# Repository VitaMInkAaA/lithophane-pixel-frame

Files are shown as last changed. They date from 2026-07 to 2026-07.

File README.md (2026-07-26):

# Lithophane Pixel Frame

A 3D-printed picture frame with a **7 × 9 WS2812 pixel matrix**, a capacitive touch
button and a self-hosted web panel — including a full **pixel-art animation editor**
that runs in your phone's browser. No cloud, no app, no external services: the
Raspberry Pi Pico W serves everything itself.

Draw frame by frame on your phone, apply effects, hit play, and the drawing appears
on the lamp in real time.






> 🇵🇱 Pełna dokumentacja po polsku: **[DOKUMENTACJA.md](DOKUMENTACJA.md)**

---

## Features

- **17 built-in modes** — fire, candle flame, aurora, plasma, rainbow, rainbow from
  the corner, snow, Matrix rain, sparkles, fireflies, trailing balls, bouncing cube,
  fireworks, beating heart, breathing, solid colour and a calibration pattern —
  all written for a portrait 7 × 9 grid
- **Pixel-art editor in the browser** — draw with your finger, flood fill,
  eyedropper, undo/redo, onion skin of the previous frame
- **Frame-by-frame animation** — per-frame duration, timeline with thumbnails,
  live preview on both the phone and the lamp
- **Effects** — brightness, invert, desaturate, saturate, contrast, tint;
  applied to one frame, a range, or the whole animation
- **Frame generators** — fade in/out, cross-fade, blink, auto-movement,
  ping-pong, reverse, speed up/down
- **Gallery** — save animations on the device, pick which ones the touch button
  cycles through
- **Touch control** — 1/2/3/4 clicks and press-and-hold ramps for brightness and speed
- **Zero-config networking** — connects to your Wi-Fi, falls back to its own
  access point with a captive portal, reachable at `lampka.local`
- **Auto-off timer**, on-device event log, and a self-healing HTTP listener
- **No external libraries.** Everything runs on stock MicroPython.

---

## Bill of materials

| # | Part | Qty | Notes |
|---|---|---|---|
| 1 | **Raspberry Pi Pico W** | 1 | Wi-Fi is required. Pico 2 W works too. Plain Pico won't — no radio. |
| 2 | **WS2812B LED strip** | 63 LEDs | Cut into segments and glued in a serpentine. 60 LEDs/m gives ~16.7 mm pitch → ~117 × 150 mm active area. |
| 3 | **TTP223 capacitive touch module** | 1 | Momentary mode (factory default). Latching mode will **not** work. |
| 4 | **5 V power supply** | 1 | ≥ 3 A for full brightness, 2 A is enough at the default 40 %. |
| 5 | **Wire** | — | AWG 20 (0.5 mm²) for power, AWG 24–26 for data. |
| 6 | **3D-printed enclosure** | 3 parts | STL files in [`cad/`](cad/) — main case, back cover, Pico cover. |
| 7 | **Lithophane panel** | 1 | Printed from your own photo, see below. |

### Optional

The reference build runs fine without these. They are common good practice and worth
adding if you hit the matching problem:

| Part | What it is for |
|---|---|
| **Schottky diode** 1N5817 / SS14, ≥ 1 A | On `VSYS`, so the external supply and USB can both be connected at once |
| **Resistor 330 Ω** | In series with the data line at the first LED — damps reflections on long data runs |
| **Capacitor 470–1000 µF**, ≥ 6.3 V | Across 5 V and GND at the matrix input — absorbs current surges when many LEDs switch at once |
| **74AHCT125** level shifter | Only if the LEDs misbehave on 3.3 V data (see [Troubleshooting](#troubleshooting)) |

---

## 3D-printed parts

Everything for the enclosure lives in **[`cad/`](cad/)**:

| File | What it is |
|---|---|
| `stl/case-main.stl` | Main enclosure — holds the matrix and the electronics |
| `stl/cover.stl` | Back cover |
| `stl/cover-pico.stl` | Cover over the Pico |

Printed flat, the parts need no supports. Material and colour are up to you — light
passes through the lithophane, not through the enclosure.

The **lithophane panel itself is not in the repository** — you generate it from your
own photo, as described below.

---

## The lithophane panel

The frame is built for a **portrait photo in 3:4 proportion** — straight out of an
iPhone, or any image with the same aspect ratio. A landscape or square photo will not
fit the frame; crop it to portrait 3:4 first.

Generate the model with **[itslitho](https://tool.itslitho.com/CreateModel)** using
these settings:

| Section | Setting | Value |
|---|---|---|
| **Shape** | Shape | `Arc` |
| | Height | `150 mm` |
| | Width | *auto* (≈ 109.5 mm — derived from the photo's aspect ratio) |
| | Angle | `50°` |
| | Min thick | `0.8 mm` |
| | Max thick | `3.2 mm` |
| | Crop / Inside | off |
| **Frame** | Frame | `Frame` |
| | Thickness | `3 mm` |
| | Depth | `4 mm` |
| | Angle | `45°` |
| | Advanced | off |
| **Quality** | mm per pixel | `0.1 mm` |
| | Preview model | `Low` |
| **Attributes** | Enable lamp / Close bottom / Nightlight | all off |
| **Model** | Lighting | `Back lighted` |
| | Light intensity | `5 – 95 %` |
| | Auto update / Cura fix | on |
| **Image** | Positive image | on |
| | Flip / Mirror image | off |
| | Placement horizontal / vertical | `50 % / 50 %` |
| | Zoom factor | `100 %` |

Notes:

- **Min 0.8 mm / max 3.2 mm** is what makes the image readable when backlit — thin
  spots let light through, thick ones block it. Thinner than 0.8 mm becomes fragile
  and prints badly.
- `Back lighted` matters: the tool inverts the depth map for a panel lit from behind,
  which is exactly how the LED matrix sits.
- At `0.1 mm per pixel` the exported STL is around **165 MB**. That is normal for a
  lithophane — slicing it takes a while.
- Print in **white or natural PLA**, no supports needed for the arc shape. The curve
  is deliberate: it keeps the panel away from the LEDs so individual pixels blur into
  an even glow instead of showing as dots.

---

## Wiring

| Signal | Pico W pin | Notes |
|---|---|---|
| Matrix `DIN` | **GP0** — pin 1 | Optionally through a 330 Ω resistor |
| TTP223 `OUT` | **GP2** — pin 4 | |
| TTP223 `VCC` | **3V3(OUT)** — pin 36 | **Not 5 V** — Pico GPIO is not 5 V tolerant |
| Common ground | **GND** — pin 38 | Supply, Pico and matrix must share ground |
| Pico power | **VSYS** — pin 39 | Optionally via a Schottky diode |
| Matrix power | Straight from the PSU | Separate pair of wires |

```
                    ┌──────────── (thick pair) ──────► matrix  5V / GND
   5 V PSU ─────────┤
                    └───────────────────────────────► VSYS (pin 39)
                        (optional Schottky here, so USB
                         can stay plugged in at the same time)

   Pico GP0 ──────────────────────────────────► DIN (first LED)
   Pico GND ──────────────────────────────────► GND  (shared!)
```

### Power notes

- **Never feed 5 V into `VBUS` (pin 40)** — it is wired directly to the USB
  connector and would back-feed your computer's port.
- **Never feed 5 V into `3V3(OUT)` (pin 36)** — that pin is an output and 5 V kills it.
- Feeding `VSYS` directly works. Add a Schottky diode there if you want the external
  supply and USB connected at the same time — then the two sources can't fight
  each other.
- Wire the power in a **star** from the PSU. Don't daisy-chain the Pico behind the
  matrix: several amps of pulsing current through a thin wire cause voltage dips
  that reset the Pico mid-animation.
- 63 LEDs at full white draw ≈ **3.8 A**. The web panel shows the estimated draw
  next to the brightness slider.

### Matrix geometry

The firmware ships configured for a strip that **starts in the bottom-right corner**
(viewed from the front), runs **upwards**, turns around and comes back down — i.e.
serpentine columns of 9.

If yours is soldered differently, don't guess: open **Settings → Matrix geometry →
Wizard** in the panel. It lights individual LEDs *by strip index* (bypassing the
mapping entirely), asks two questions about what you see, and derives the correct
settings itself.

---

## Installation

You need MicroPython for **Pico W**. The `neopixel` and `network` modules ship with
the firmware — there is nothing to install.

Everything under [`firmware/`](firmware/) goes onto the device, keeping the same
layout — `.py` files in the device root, the panel in a `www` folder:

```bash
cd firmware
mpremote connect auto fs mkdir :www
mpremote connect auto fs cp *.py :
mpremote connect auto fs cp www/index.html www/style.css www/app.js :www/
mpremote connect auto reset
```

Using Thonny: copy the contents of `firmware/` to the device, preserving the `www`
subfolder.

Nothing outside `firmware/` belongs on the Pico — `cad/` holds the printable models.

---

## First run

With no Wi-Fi credentials stored, the lamp creates its own network:

- **SSID:** `LED-Lampka` · **password:** `ledlampka`
- **Panel:** <http://192.168.4.1/>

Connect your phone — on most devices the panel opens by itself (captive portal).
Go to the **WiFi** tab, pick your network, enter the password. The lamp connects
**immediately, without rebooting**, and shows the result. If it fails, it tells you
*why* (`wrong password`, `network not visible`, …), keeps its own access point alive,
and stays reachable so you can fix the password on the spot.

### Finding the lamp afterwards

| Method | Address |
|---|---|
| Hostname (mDNS) | <http://lampka.local/> |
| Its own access point | <http://192.168.4.1/> |
| The matrix tells you | last two octets of the IP, digit by digit |

The matrix shows **two** octets rather than one on purpose: a router may put the
lamp on a different subnet than your phone, and a lone `144` would send you to the
wrong address.

---

## Touch control

| Gesture | Action |
|---|---|
| **1 click** | On / off |
| **2 clicks** | Next mode |
| **3 clicks** | Previous mode |
| **4 clicks** | Show IP on the matrix |
| **Press and hold** | Brightness ramp — release and hold again to reverse direction |
| **2 clicks + hold** | Animation speed, same alternating ramp |
| **3 clicks + hold 5 s** | Forget Wi-Fi and return to access-point mode |

A single click reacts after ~0.35 s — that is the window for a second click, without
which one and two clicks cannot be told apart. Wiping the Wi-Fi credentials
deliberately requires three clicks *and* a long hold, so a plain long press (which
controls brightness) can never erase your network by accident.

If your TTP223 has inverted logic (jumper), flip it in **Settings → Button** —
no rewiring needed.

---

## Web panel

**Modes** — brightness, speed, colour, mode grid. The colour tile greys out and
locks in modes that paint their own colours.

**Editor** — a full pixel-art tool:

- 7 × 9 grid mapped 1:1 to the frame, brush + palette, flood fill, eyedropper,
  eraser, undo/redo (40 steps), onion skin of the previous frame
- Frame strip with thumbnails; add, duplicate, reorder, delete, wipe all
- Per-frame duration in milliseconds
- **Effects** applied to *this frame / from here on / all frames*: brightness
  0–200 %, invert, desaturate, saturate, contrast, tint with the brush colour
- **Transforms**: shift in four directions (wrapping), mirror, rotate 180°
- **Generators**: fade in/out, cross-fade to the next frame, blink, auto-movement,
  ping-pong, reverse, ×2 faster/slower
- **Preview** plays on the phone grid and on the lamp at once; stop restores both
  the frame you were editing and what the lamp was showing before

**Gallery** — saved animations with thumbnails, plus a checklist deciding which
modes the touch button cycles through.

**Settings** — auto-off timer, hostname, access-point behaviour, matrix geometry
wizard, button logic, diagnostics.

**WiFi** — status with signal strength, every address the lamp answers on, network
scan, country code. A weak link raises a warning banner here and in Settings, since
that is where you would go to do something about it.

### Why the effects don't slow the lamp down

All image processing happens **in the browser** and is baked into pixels. The Pico
receives finished frames and does exactly what it does for a static image: one
189-byte `blit()` per frame. You can stack as many effects as you like — the cost on
the device never changes.

Limits that protect the device: **40 frames** per animation, **24 animations** in the
gallery, frame duration **40–10000 ms**, and a **64 kB** cap on request bodies.
Only the currently playing animation is held in RAM.

---

## Writing your own animation

Add a class to `animations.py` and register it in `ANIMS` — the panel picks it up
automatically:

```python
class MyAnimation(Anim):
    name = "mine"            # ASCII id used by the API
    label = "My animation"   # shown in the panel
    interval = 60            # ms between steps at 100 % speed
    uses_color = False       # True if it uses the colour picked in the panel

    def step(self):
        m = self.m
        m.clear()
        m.set(3, 4, 255, 0, 0)   # x, y, r, g, b — (0,0) is the top-left corner
```

Do not call `m.show()` or `time.sleep()` — the render loop in `lamp.py` handles both,
which is why brightness and speed work globally for every effect. Available helpers:
`clear()`, `fill()`, `set()`, `setc()`, `get()`, `add()`, `fade()`, `scale()`,
`blit()`, plus `m.w` and `m.h`.

---

## Project structure

```
firmware/            everything that goes onto the Pico
├── main.py          startup: Wi-Fi, boot signals, task launch
├── config.py        pins, matrix size, settings + settings.json
├── led_matrix.py    Matrix class: one NeoPixel object, serpentine mapping, brightness
├── animations.py    all animations (Anim base class + ANIMS registry)
├── lamp.py          lamp state, render loop, auto-off, gesture handling
├── touch.py         TTP223: click counting and press-and-hold
├── netmgr.py        Wi-Fi connect, access point, scan, reconnect watchdog
├── webserver.py     HTTP server + REST API (uasyncio, no external libraries)
├── dns.py           DNS responder for the captive portal
├── frames.py        gallery of saved animations (anims/ directory)
├── glyphs.py        3 × 5 font for showing the IP on the matrix
├── logger.py        event log: serial always, log.txt optionally
└── www/             panel: index.html, style.css, app.js
cad/                 enclosure: STL files, ready to print
```

`settings.json`, `anims/` and `log.txt` are created on the device at runtime, which
is why they are in `.gitignore`.

---

## Troubleshooting

| Symptom | Cause and fix |
|---|---|
| Animations look shredded or move the wrong way | Wrong geometry — run **Settings → Geometry → Wizard** |
| Random flicker, wrong colours | Power. Check the capacitor, common ground and wire gauge. If it persists, add a 74AHCT125 level shifter on the data line |
| Pico resets on bright animations | PSU too weak, or the Pico is daisy-chained behind the matrix — wire in a star |
| Lamp has an IP but the panel won't open | See below |
| `lampka.local` doesn't resolve | Your firmware lacks the mDNS responder, or the client doesn't support it. Use the IP or the access point |
| Phone can't reach it while the computer can | Compare subnets, and check for client isolation on the router |

### If the panel stops responding after hours of uptime

Three known causes, all addressed in the firmware:

1. **Wi-Fi power saving.** The CYW43 sleeps the receiver between frames and drops
   inbound packets — the lamp looks connected but is unreachable. Disabled by default.
2. **No reconnect.** After a router restart or lease expiry the lamp used to stay
   offline forever. A watchdog now checks every 20 s and reconnects.
3. **The HTTP listener dying.** In uasyncio the accept loop is an ordinary task; if
   it raises, it dies silently while animations keep running. A supervisor probes
   the port every 2 minutes and restarts the listener — no reboot, no interruption.

Enable **Settings → Diagnostics** to write events to `log.txt` on the device. Read it
with `mpremote connect auto fs cat :log.txt`, in the panel, or over serial. Each entry
is stamped with uptime, because the Pico has no battery-backed clock. The periodic
status line tells the three causes apart:

```
02:35:11  RAM 138912 B | polaczenia otwarte 0 | obsluzonych 214
```

Falling RAM means a leak; a rising open-connection count means sockets aren't being
released; a frozen served counter means requests aren't arriving at all.

More detail — including every failure mode and the reasoning behind each fix — is in
**[DOKUMENTACJA.md](DOKUMENTACJA.md)**.

---

## Development

The firmware is plain Python, so most of it runs on a desktop. The test suites
replace `machine`, `neopixel` and `network` with stubs that **validate** instead of
merely pretending — the NeoPixel stub raises if a channel leaves 0–255 or an index
falls outside the matrix, so running the animations through it catches real bugs.

- `asyncio.start_server` works on CPython, so the HTTP and DNS servers are tested
  over **real sockets** with real requests
- The button tests drive a **controlled clock**, making a 5-second hold deterministic
- The browser tests extract functions **verbatim from `firmware/www/app.js`** and run them in
  Node, so they exercise the shipped code rather than a copy

What the tests cannot prove: LED timing, current draw, real Wi-Fi behaviour, RAM
pressure and speed on a 133 MHz target, or how anything actually looks. Those need
the hardware.

---

## License

**[CC BY-NC 4.0](LICENSE)** — Creative Commons Attribution-NonCommercial 4.0
International.

Build it for yourself, modify it, publish your version with credit, use it in
workshops and education. **Selling assembled lamps, kits or printed panels requires
written permission** from the copyright holder.

Note that CC BY-NC is deliberately *not* an OSI-approved open-source license — the
non-commercial restriction is the point. Third-party components (MicroPython, the
Pico W SDK, external tools referenced here) keep their own licenses.

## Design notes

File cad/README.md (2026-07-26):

# CAD — model obudowy / enclosure model

Pliki do druku 3D. **3D-printable parts.**

| Plik / File | Co to / What it is |
|---|---|
| `stl/case-main.stl` | Obudowa główna — mieści matrycę i elektronikę. *Main enclosure, holds the matrix and electronics.* |
| `stl/cover.stl` | Pokrywa tylna. *Back cover.* |
| `stl/cover-pico.stl` | Pokrywa nad Pico. *Cover over the Pico.* |

Folder nazywa się `cad`, a nie `fusion`, bo pliki STL otworzy i wydrukuje każdy,
niezależnie od tego, w czym projektuje.

*The folder is called `cad`, not `fusion`: STL files are usable by anyone, whatever
CAD package they run.*

## Druk / Printing

Części nie wymagają podpór drukowane płasko. Materiał i kolor dowolne — światło idzie
przez litofanię, nie przez obudowę.

*No supports needed when printed flat. Material and colour are up to you — light
passes through the lithophane, not through the enclosure.*

## Panel z litofanią / The lithophane panel

**Nie ma go tutaj i nie powinno być** — generujesz go ze swojego zdjęcia. Ustawienia
narzędzia [itslitho](https://tool.itslitho.com/CreateModel) są w
[README](../README.md#the-lithophane-panel).

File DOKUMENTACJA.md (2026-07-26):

# LED Lampka — ramka 7 × 9 na Raspberry Pi Pico W

Drukowana w 3D ramka z matrycą WS2812 **7 szeroko × 9 wysoko (63 diody)**, przyciskiem
dotykowym TTP223 i panelem WWW. Sterowanie dotykiem albo z telefonu — bez chmury,
wszystko lokalnie na Pico.

## Podłączenie

| Sygnał | Pico | Uwagi |
|---|---|---|
| DIN matrycy | **GP0** (pin 1) | opcjonalnie rezystor 330 Ω w szereg przy pierwszej diodzie |
| OUT z TTP223 | **GP2** (pin 4) | |
| VCC TTP223 | **3V3(OUT)** (pin 36) | **nie 5 V** — GPIO Pico nie jest 5 V tolerant |
| GND wszystkiego | GND (pin 38) | masa wspólna z zasilaczem |
| zasilanie Pico | **VSYS** (pin 39) | opcjonalnie przez diodę Schottky |
| zasilanie matrycy | osobna para przewodów wprost od zasilacza | |

### Elementy opcjonalne

Referencyjny egzemplarz działa bez nich. To dobra praktyka, warta dołożenia,
jeśli natkniesz się na odpowiadający jej problem:

| Element | Po co |
|---|---|
| **dioda Schottky** 1N5817 / SS14, ≥ 1 A | na `VSYS`, żeby dało się mieć podłączony zasilacz i USB jednocześnie |
| **rezystor 330 Ω** | w szereg z linią danych przy pierwszej diodzie — tłumi odbicia przy dłuższym przewodzie |
| **kondensator 470–1000 µF**, ≥ 6,3 V | między 5 V i GND na wejściu matrycy — przyjmuje skoki prądu przy przełączaniu wielu diod naraz |
| **konwerter poziomów 74AHCT125** | tylko jeśli diody wariują przy danych 3,3 V |

Taśma naklejona wężykiem: **pierwsza dioda w prawym dolnym rogu** (patrząc na ramkę
z przodu), pasek idzie **w górę**, zawraca i schodzi w dół — czyli kolumnami po 9.
Tak jest ustawione fabrycznie w `config.py`. Kod przelicza to na współrzędne (x, y)
z zerem w lewym górnym rogu, więc animacje pisze się normalnie, bez myślenia o wężyku.
Jeśli Twoja ramka jest polutowana inaczej, nie zgaduj — uruchom **Kreator** w panelu
(Ustawienia → Geometria), odpowiedz na dwa pytania o to, co widzisz, i ustawi się sam.

63 diody na pełnej bieli to ~3,8 A. Domyślna jasność 40 % daje ~1,5 A, a panel pokazuje
szacowany pobór przy każdej zmianie suwaka.

## Model do druku

Wszystko do obudowy leży w folderze **`cad/`**:

| Plik | Co to |
|---|---|
| `stl/case-main.stl` | obudowa główna — mieści matrycę i elektronikę |
| `stl/cover.stl` | pokrywa tylna |
| `stl/cover-pico.stl` | pokrywa nad Pico |

Drukowane płasko części nie wymagają podpór. Materiał i kolor dowolne — światło idzie
przez litofanię, nie przez obudowę.

Folder nazywa się `cad`, a nie `fusion`, bo pliki mają służyć też komuś bez
Fusion 360. Nazwa związana z jednym programem sugerowałaby, że bez niego nie ma tu
czego szukać.

**Samego panelu z litofanią w repozytorium nie ma** — generujesz go ze swojego
zdjęcia, patrz niżej.

## Litofania (panel ze zdjęciem)

Ramka jest zrobiona pod **zdjęcie pionowe w proporcji 3:4** — prosto z iPhone'a albo
dowolne o tej samej proporcji. Zdjęcie poziome ani kwadratowe **nie zmieści się**
w ramce; najpierw przytnij je do pionu 3:4.

Model generujesz na **<https://tool.itslitho.com/CreateModel>** z takimi ustawieniami:

| Sekcja | Ustawienie | Wartość |
|---|---|---|
| **Shape** | Shape | `Arc` |
| | Height | `150 mm` |
| | Width | *automatycznie* (~109,5 mm — wynika z proporcji zdjęcia) |
| | Angle | `50°` |
| | Min Thick | `0,8 mm` |
| | Max Thick | `3,2 mm` |
| | Crop / Inside | wyłączone |
| **Frame** | Frame | `Frame` |
| | Thickness | `3 mm` |
| | Depth | `4 mm` |
| | Angle | `45°` |
| | Advanced | wyłączone |
| **Quality** | mm per pixel | `0,1 mm` |
| | Preview Model | `Low` |
| **Attributes** | Enable lamp / Close bottom / Nightlight | wszystko wyłączone |
| **Model** | Lighting | `Back lighted` |
| | Light intensity | `5 – 95 %` |
| | Auto update / Cura fix | włączone |
| **Image** | Positive image | włączone |
| | Flip / Mirror image | wyłączone |
| | Placement horizontal / vertical | `50 % / 50 %` |
| | Zoom factor | `100 %` |

Dlaczego akurat tak:

- **0,8–3,2 mm grubości** to jest cały mechanizm litofanii — cienkie miejsca
  przepuszczają światło, grube blokują. Poniżej 0,8 mm panel robi się kruchy i źle
  się drukuje.
- `Back lighted` jest istotne: narzędzie odwraca wtedy mapę grubości pod panel
  podświetlany od tyłu, czyli dokładnie tak, jak siedzi matryca.
- Przy `0,1 mm na piksel` plik STL ma około **165 MB**. To normalne dla litofanii,
  ale krojenie chwilę trwa.
- Drukuj w **białym albo naturalnym PLA**, łuk nie wymaga podpór. Wygięcie panelu
  jest celowe: odsuwa go od diod, dzięki czemu pojedyncze piksele rozmywają się
  w równą poświatę zamiast świecić jako kropki.

## Wgranie na Pico

Potrzebny MicroPython dla **Pico W** (biblioteki `neopixel` i `network` są w firmware,
nic nie doinstalowujesz).

Na Pico trafia **cała zawartość folderu `firmware/`**, z zachowaniem układu — pliki
`.py` do katalogu głównego, panel do katalogu `www`:

```bash
cd firmware
mpremote connect auto fs mkdir :www
mpremote connect auto fs cp *.py :
mpremote connect auto fs cp www/index.html www/style.css www/app.js :www/
mpremote connect auto reset
```

W Thonnym: skopiuj zawartość `firmware/` na urządzenie, zachowując podkatalog `www`.

Nic spoza `firmware/` na Pico nie idzie — `cad/` to modele do druku.

## Pierwsze uruchomienie

Bez zapisanego hasła lampka stawia własną sieć:

- SSID **LED-Lampka**, hasło **ledlampka**
- panel: **http://192.168.4.1/**

Podłącz się telefonem, wejdź w zakładkę **WiFi**, wybierz swoją sieć, podaj hasło →
lampka próbuje się połączyć **od razu, bez restartu**, a wynik widać w polu „Stan".
Jeśli się nie uda, pokazuje **dlaczego** („złe hasło", „nie widzę tej sieci"…),
nie traci własnej sieci i panel zostaje dostępny, więc możesz od razu poprawić hasło.

### Gdy lampka nie chce się połączyć

| Komunikat | Co z tym zrobić |
|---|---|
| złe hasło | literówka; hasła WiFi rozróżniają wielkość liter |
| nie widzę tej sieci | **Pico W obsługuje wyłącznie 2,4 GHz** — sieć 5 GHz jest dla niego niewidzialna, nawet jeśli telefon ją widzi. Sprawdź też kod kraju niżej |
| router odrzucił połączenie | filtr adresów MAC albo pełna lista klientów na routerze |
| nie zdążyłem w wyznaczonym czasie | słaby sygnał — spróbuj bliżej routera |
| sieć nie przydzieliła adresu | problem z DHCP na routerze |

**Kod kraju** (zakładka WiFi, domyślnie `PL`) decyduje o dozwolonych kanałach.
Bez niego Pico trzyma się kanałów 1–11, a routery w Polsce potrafią stać na 12 lub 13
— takiej sieci lampka **w ogóle nie zobaczy**, i to wygląda dokładnie jak „nie widzę
tej sieci". Jeśli sieć jest widoczna na telefonie, a lampka jej nie znajduje,
to jest pierwszy podejrzany.

## Jak wejść do panelu nie znając adresu IP

Trzy niezależne drogi — jeśli jedna zawiedzie, zostają dwie:

**1. Nazwa lampki (mDNS): http://lampka.local/**
Nazwę zmienisz w Ustawieniach. Działa bez zaglądania do rutera. iPhone i Mac
obsługują to od zawsze (Bonjour), Windows 10/11 i Android 12+ też. Zastrzeżenie:
wymaga firmware'u z odpowiedzią mDNS — buildy MicroPythona dla Pico W zwykle ją mają,
ale nie sprawdzę tego bez Twojego sprzętu. Po starcie lampka wypisuje na porcie
szeregowym dokładny adres, pod którym się ogłasza.

**2. Własna sieć lampki: http://192.168.4.1/**
Gdy lampka nie ma z czym się połączyć, sama stawia AP `LED-Lampka` — podłączasz
telefon i wchodzisz na `192.168.4.1`. Działa bez rutera i bez nazwy .local.

Opcja *„Trzymaj własną sieć lampki cały czas"* (domyślnie włączona) utrzymuje ten AP
**równolegle** z domowym WiFi — drugie, niezależne wejście do panelu, przydatne tam,
gdzie nie masz dostępu do rutera. Zastrzeżenie: Pico W dzieli jedno radio między oba
interfejsy, więc na niektórych routerach potrafi to rozchwiać połączenie. Jeśli lampka
ma poprawny adres, a panel nie odpowiada — to jeden z podejrzanych, spróbuj wyłączyć.

**3. Panel otwiera się sam po podłączeniu do sieci lampki**
Domyślnie włączone (Ustawienia → *„Otwieraj panel sam po podłączeniu"*). Telefon po
połączeniu z siecią `LED-Lampka` sprawdza dostęp do internetu, a lampka odpowiada na
każde pytanie DNS swoim adresem i odbija zapytanie na panel — system pokazuje go od
razu, jak w hotelowym WiFi.

Działa **wyłącznie w czystym trybie AP**, czyli gdy lampka nie jest w żadnej sieci.
Po wejściu do domowego WiFi serwer DNS się nie uruchamia — odpowiadanie „każda nazwa
= 192.168.4.1" na cudzej sieci zepsułoby internet pozostałym urządzeniom.

**4. Lampka sama pokazuje swój adres**
Po połączeniu z WiFi matryca wyświetla **dwa ostatnie człony** adresu, rozdzielone
poziomą kreską — np. `1`,`7`,`8`, kreska, `1`,`4`,`4` znaczy `192.168.178.144`.
Dwa człony, a nie jeden, bo router potrafi wpuścić lampkę do innej podsieci niż ta,
w której jest Twój telefon — wtedy samo `144` prowadziłoby pod zły adres.

Awaryjnie: **4 kliknięcia** pokazują końcówkę IP na matrycy w dowolnym momencie,
a **3 kliknięcia + przytrzymanie 5 s** czyszczą zapisane WiFi i lampka wraca do
czystego trybu AP pod `192.168.4.1`.

Sygnały po starcie:

| Błysk | Znaczenie |
|---|---|
| słaby niebieski | kod wystartował |
| żółty | łączę się z zapisaną siecią |
| zielony | jest WiFi, potem matryca pokazuje **dwa ostatnie człony IP** |
| dwa niebieskie | tryb AP |
| trzy czerwone | wyjątek w kodzie (szczegóły na porcie szeregowym) |

## Sterowanie dotykiem

| Gest | Efekt |
|---|---|
| **1 klik** | włącz / wyłącz |
| **2 kliki** | następny tryb (gdy zgaszona — zapala) |
| **3 kliki** | poprzedni tryb |
| **4 kliki** | pokaż końcówkę IP na matrycy |
| **przytrzymanie** | jasność — rampa w górę; puszczasz i trzymasz znowu, żeby zejść w dół |
| **2 kliki + przytrzymanie** | szybkość animacji, tak samo naprzemiennie |
| **3 kliki + przytrzymanie 5 s** | zapomnij WiFi i wróć do trybu AP |

Jak to działa w praktyce: pojedynczy klik reaguje po ~0,35 s, bo tyle trwa okno na
dołożenie drugiego kliknięcia — inaczej nie da się odróżnić jednego od dwóch.
Rampa jasności rusza po 0,5 s trzymania i idzie ~4 % na 0,1 s, czyli pełen przejazd
od 1 % do 100 % trwa około 2,5 s. Kierunek przełącza się po każdym puszczeniu, a po
dojściu do końca zakresu następne trzymanie zawsze zawraca. Jasność nie schodzi
poniżej 1 %, żeby lampka nie „zgasła" bez wyłączenia.

Gest kasowania WiFi celowo wymaga trzech kliknięć i dopiero potem 5 s trzymania —
samo długie trzymanie steruje jasnością i nie ma szans przypadkiem wyczyścić sieci.

Jeśli Twój moduł TTP223 ma odwróconą logikę (zworka), przełącz to w panelu w
**Ustawienia → Przycisk i start** — nic nie trzeba przelutowywać.

## Panel WWW

**Animacje** — jasność, szybkość, kolor (paleta + własny picker), siatka trybów.

**Edytor** — pełne narzędzie do pixel artu i animacji klatka po klatce.

*Rysowanie:* siatka 7 × 9 1:1 z ramką, pędzel z paletą, **wypełnianie obszaru**,
**pipeta** (pobiera kolor z siatki), gumka, cofnij/ponów (40 kroków wstecz).
**Duch poprzedniej klatki** pokazuje pod spodem przygaszony poprzedni kadr — bez
tego rysowanie ruchu to zgadywanka. Klik w piksel z kolorem pędzla gasi go; kolor
pociągnięcia ustala się przy pierwszym dotkniętym pikselu, więc przeciągnięcie po
pomalowanym fragmencie go nie zjada, a zaczęte na świecącym pikselu działa jak gumka.

*Klatki:* pasek miniatur, dodaj / duplikuj / przesuń / usuń, **usuń wszystkie**
(z pytaniem o potwierdzenie, cofalne), własny czas każdej klatki w ms,
„ten czas wszystkim".

Pod siatką, w zasięgu kciuka, jest wszystko, czego używa się przy rysowaniu animacji:
strzałki **◀ ▶** do przewijania klatka po klatce ze wskaźnikiem pozycji (`3 / 12`),
przyciski **▶ Podgląd**, **+ klatka**, **duplikuj**, **Cofnij**, **Ponów** oraz
osobny rządek **← ↑ ↓ →** do przesuwania rysunku. Pełne trójkąty przewijają klatki,
cienkie strzałki przesuwają obraz — to celowo różne kształty. Przewijanie klatek
zawija się, bo animacja i tak jest pętlą.

**▶ Podgląd** odtwarza animację na siatce w telefonie, a przy zaznaczonym
*„Podgląd puszczaj też na lampce"* równocześnie na ramce — widzisz wtedy dokładnie
to samo w obu miejscach. Po odznaczeniu podgląd zostaje tylko w telefonie, a lampka
gra dalej swoje. **Stop** wraca do klatki, którą edytowałeś, a lampka do tego, co
pokazywała przed podglądem (o ile w ogóle brała udział). Podgląd niczego nie zmienia
w animacji. Przerwanie go rysowaniem, przewinięciem albo kliknięciem w inną klatkę
zatrzymuje odtwarzanie tam, gdzie jesteś, bez skakania.

*Efekty* — z wyborem zakresu **tej klatki / od tej do końca / wszystkich klatek**:
jasność suwakiem 0–200 % plus szybkie −20 % / +25 %, negatyw, odbarwienie,
nasycenie, kontrast, zabarwienie kolorem pędzla.

*Przekształcenia:* przesuwanie w czterech kierunkach (z zawijaniem), odbicie
poziome i pionowe, obrót 180°.

*Generowanie klatek:* ściemnianie, rozjaśnianie, **przenikanie do następnej klatki**,
miganie, przesuwanie (auto-animacja ruchu w zadanym kierunku), „tam i z powrotem",
odwrócenie kolejności, przyspieszenie i zwolnienie całości ×2.

**Galeria** — zapisane animacje z miniaturami: pokaż na lampce, wczytaj do edytora,
usuń. Niżej **sekwencja przycisku**: lista wszystkich trybów z checkboxami. Zaznaczone
krążą pod dwoma kliknięciami przycisku, odznaczone zostają dostępne z panelu, ale
przycisk je pomija. Domyślnie poza sekwencją jest tylko Kalibracja.

**Ustawienia** — auto-wyłączanie (włącznik + liczba minut; licznik zeruje każde
dotknięcie przycisku i każda zmiana w panelu), nazwa lampki, stały AP i automatyczne
otwieranie panelu, geometria matrycy z kreatorem, logika przycisku, restart.

Kafelek koloru **wyszarza się i blokuje** w trybach, które mają własne kolory —
działa tylko przy „Kolor stały" i „Oddech", żeby nie kręcić suwakiem bez efektu.

**WiFi** — stan wraz z siłą sygnału, wszystkie adresy pod którymi lampka odpowiada
(klikalne), skan sieci, zapis, „zapomnij sieć".

Przy słabym sygnale na górze zakładek **WiFi** i **Ustawienia** pojawia się baner
z konkretną wartością w dBm. Tylko tam — w Trybach, Edytorze i Galerii nie ma czego
z tym zrobić, więc nie zabiera miejsca. Poniżej −70 dBm ostrzeżenie jest łagodne,
poniżej progu `rssi_min` robi się czerwone i tłumaczy, że pakiety giną.

Ustawienia lądują w `settings.json`, ale zapis na flash jest zbierany i wykonywany
najwyżej raz na 5 s — klikanie przyciskiem nie zajeżdża pamięci.

## Animacje

Stare (przepisane na 7 × 9 z poprawnym mapowaniem): **Tęcza**, **Tęcza z rogu**,
**Śnieg**, **Matrix**, **Kostka**, **Świetliki**, **Kulki z ogonami**.

Nowe, dobrane pod pionową ramkę 7 × 9:

| Tryb | Dlaczego pasuje |
|---|---|
| **Ogień** | algorytm Fire2012 per kolumna — na pionowej ramce wygląda najlepiej z całej listy |
| **Płomień świecy** | ciepłe migotanie, jaśniej u dołu i na środku; tryb „lampka do pokoju" |
| **Zorza polarna** | wolne zielono-błękitne fale, spokojne światło |
| **Plazma** | gładkie przejścia kolorów, klasyk demoscenowy |
| **Iskry** | losowe błyski gasnące wykładniczo |
| **Fajerwerki** | rakieta leci w górę i wybucha — 9 rzędów wysokości robi tu robotę |
| **Bijące serce** | bitmapa 7 × 9 z podwójnym uderzeniem, dobre na prezent |
| **Oddech** | pulsowanie wybranym kolorem |
| **Kolor stały** | zwykła lampka w wybranym kolorze |
| **Kalibracja** | biała kropka wędrująca rzędami + znaczniki rogów |

Czego nie ma i dlaczego: **przewijany tekst** (7 diod szerokości to pół litery — dałoby
się tylko pionowo, mało czytelne), **reakcja na muzykę** (potrzebny moduł mikrofonu,
np. MAX9814 na ADC), **kolory z pogody** (wymaga odpytywania API w tle). Wszystkie trzy
da się dorobić na tej architekturze — animacja to jedna klasa z metodą `step()`.

## Jak dopisać własną animację

W `animations.py` dodaj klasę i wpisz ją do `ANIMS` — panel podchwyci ją sam:

```python
class MojaAnimacja(Anim):
    name = "moja"           # ASCII, identyfikator w API
    label = "Moja animacja" # to widać w panelu
    interval = 60           # ms między krokami przy szybkości 100 %

    def step(self):
        m = self.m
        m.clear()
        m.set(3, 4, 255, 0, 0)   # x, y, r, g, b — (0,0) to lewy górny róg
```

Nie wołaj `m.show()` ani `time.sleep()` — robi to pętla w `lamp.py`. Do dyspozycji
masz `m.clear()`, `fill()`, `set()`, `setc()`, `get()`, `add()`, `fade()`, `scale()`
oraz `m.w`, `m.h`.

## Co było nie tak w starej wersji

1. **Każdy plik animacji tworzył własny obiekt `NeoPixel` na GP0** — było 7 niezależnych
   buforów walczących o ten sam pasek. To dlatego jasność nie działała (komentarz
   „janosc nie dziala" na końcu starego `main.py`): `set_color()` skalowało swój bufor,
   a animacje zaraz nadpisywały diody pełnymi wartościami. Teraz jest **jeden**
   `NeoPixel` i jasność nakładana w jednym miejscu, w `Matrix.show()`.
2. Rozmiar 8 × 8 (64 diody) wpisany na sztywno w 9 plikach — teraz raz w `config.py`.
3. Niespójne mapowanie: część plików liczyła wężykiem, część liniowo. Teraz jedna
   tablica mapowania, konfigurowalna z panelu.
4. `while True` w każdym pliku — nie dało się tego użyć jako biblioteki.
5. Blokujące `time.sleep()` w pętli głównej — przy serwerze WWW to nie do przyjęcia,
   więc całość siedzi na `uasyncio`: animacje, przycisk i panel działają równolegle.
6. Stary `main.py` zapisywał tryb, przepisując `conf.py` jako kod Pythona przy każdej
   zmianie — teraz JSON, zapisywany najwyżej raz na 5 s.
7. `kub rampka.py` uznawał pozycję `[0, 0]` za „pierwsze uruchomienie", więc resetował
   animację przy każdym trafieniu w róg.

## Gdy coś nie działa

**Animacje „szatkują się", lecą w złą stronę, piksele w edytorze zapalają się nie
tam gdzie klikasz** → Ustawienia → Geometria → **Kreator**. Zapala pojedyncze diody po
numerach na taśmie (z pominięciem całego mapowania), pyta w którym rogu się zapaliły
i w którą stronę biegną, i sam wylicza wszystkie trzy ustawienia. Trzy pytania,
bez zgadywania.

Przycisk **Wzór** to sprawdzenie: poprawne mapowanie wygląda jako **biały piksel
w lewym górnym rogu**, **czerwona linia od niego w prawo** wzdłuż górnej krawędzi
i **zielona w dół** wzdłuż lewej. Nic się nie rusza — jeśli widzisz to w innych
miejscach albo poszatkowane, mapowanie jest złe.

**Diody migają losowo, złe kolory** → zasilanie. Sprawdź kondensator, wspólną masę
i przekrój przewodów. Przy 3,3 V na linii danych i 5 V na diodach czasem trzeba
konwertera poziomów albo zasilenia matrycy z 4,5 V.

**Pico się resetuje przy jaśniejszych animacjach** → zasilacz nie wyrabia albo Pico
jest podłączone za matrycą. Prowadź zasilanie gwiazdą od zasilacza.

**Przycisk reaguje odwrotnie / sam się klika** → przełącz logikę w Ustawieniach.
TTP223 potrzebuje płytki masy pod padem i nie lubi luźnego, długiego przewodu do
elektrody.

**Lampka ma adres z WiFi, ale panel nie odpowiada, a przez jej własne AP działa**
→ najpierw porównaj podsieci. Sprawdź w telefonie, jaki adres IP dostał on sam
(Android: Ustawienia → WiFi → szczegóły sieci; iPhone: WiFi → „i" przy nazwie sieci).
Jeśli telefon ma np. `192.168.1.x`, a lampka `192.168.178.x`, to **są w dwóch różnych
sieciach** i nie mają jak się widzieć — pakiety nie mają tamtędy drogi. `lampka.local`
też nie zadziała, bo mDNS jest rozgłoszeniem lokalnym i nie przechodzi między
podsieciami. Najczęstsza przyczyna: wzmacniacz zasięgu albo drugi router, który
tworzy własną sieć za NAT-em. Wtedy albo podłącz oba urządzenia do tej samej sieci,
albo po prostu korzystaj z AP lampki — po to jest.

Druga możliwość przy tych samych objawach to **izolacja klientów** na routerze
(często włączona domyślnie w sieci dla gości): urządzenia mają internet, ale nie
widzą się nawzajem. Szukaj w ustawieniach routera pozycji „izolacja klientów",
„AP isolation" albo „blokuj komunikację między urządzeniami".

**Lampka ma adres, panel działa chwilę i zamiera** → sprawdź **siłę sygnału**
w zakładce WiFi albo w logu. Poniżej −78 dBm połączenie formalnie trwa, ale ruch
przychodzący ginie i objawia się to dokładnie tak: panel się otwiera, po chwili
przestaje reagować, a odświeżenie już się nie wczytuje.

Najczęstsza przyczyna to **repeater albo mesh**: ta sama nazwa sieci leci z kilku
miejsc, a lampka przyczepia się do dalekiego nadajnika. Firmware sam temu zapobiega —
przed połączeniem skanuje eter i wybiera **konkretny, najmocniejszy** nadajnik,
zamiast zdawać się na sterownik.

Gdy sygnał spadnie poniżej progu (`rssi_min`, domyślnie −78 dBm) i utrzyma się tak
przez minutę, lampka **najpierw skanuje** i przepina się tylko wtedy, gdy naprawdę
jest do czego: kandydat musi być mocniejszy o co najmniej 6 dB. W miejscu z jednym
nadajnikiem nic nie robi — zrywanie działającego, choć słabego łącza co minutę tylko
pogorszyłoby sprawę. Zapisuje wtedy do logu:

```
sygnal slaby (-85 dBm), ale najmocniejszy dostepny nadajnik ma -85 dBm
- nie ma sensu sie przepinac, zostaje
```

i przez 10 minut nie ponawia sprawdzania, bo samo skanowanie na chwilę przerywa ruch.

Jeśli w danym miejscu sygnał jest po prostu słaby, żadne oprogramowanie tego nie
naprawi — przysuń lampkę bliżej routera albo dostaw repeater.

**Lampka jest w WiFi, ma adres, ale panel się nie otwiera** → najpewniej masz
włączone *„Trzymaj własną sieć lampki cały czas"*. Jedno radio obsługuje wtedy dwie
sieci naraz i połączenie się rozjeżdża. Wyłącz tę opcję (Ustawienia → Dostęp bez
znania adresu IP) i zrestartuj lampkę.

**Przy rysowaniu telefon przybliża stronę** → nie powinien: dwuklik jest wyłączony
przez `touch-action: manipulation`. Jeśli mimo to przybliża, masz starą wersję
`style.css` — wgraj ją ponownie. Celowe powiększenie dwoma palcami dalej działa.

**Panel wygląda inaczej niż powinien / siatka edytora jest płaska** → stara wersja
plików w pamięci przeglądarki. Pliki panelu są serwowane z `no-cache`, więc wystarczy
odświeżyć stronę; jeśli to nie pomaga, sprawdź, czy wgrałeś **wszystkie trzy** pliki
z `www/`.

**Rano/po kilku godzinach panel przestaje odpowiadać** → dwie najczęstsze
przyczyny, obie zaadresowane w kodzie:

1. **Oszczędzanie energii radia.** Układ CYW43 usypia odbiornik między ramkami
   i gubi pakiety przychodzące — lampka formalnie jest w sieci, wychodzące
   połączenia działają, ale wejść na panel się nie da. Domyślnie **wyłączone**
   (`wifi_powersave: False`, ustawiane przy każdym łączeniu). Kosztuje ~30 mA.
2. **Brak wznawiania połączenia.** Po restarcie routera, wygaśnięciu adresu albo
   zmianie kanału lampka zostawała offline do końca życia. Teraz `netmgr.watchdog`
   sprawdza stan co 20 s i sam się łączy ponownie, zapisując to w logu.

3. **Padnięcie samego nasłuchu HTTP.** W uasyncio zadanie przyjmujące połączenia
   jest zwykłym zadaniem — jeśli rzuci wyjątkiem, ginie po cichu. Animacje chodzą
   dalej, przycisk działa, a serwer po prostu przestaje odbierać. Objaw jest wtedy
   nie do odróżnienia od problemu z WiFi.

   Trzy zabezpieczenia: **dozór nasłuchu** (`Server.supervisor`) co 2 minuty puka
   do własnego portu i po dwóch nieudanych próbach restartuje nasłuch — bez
   restartu lampki i bez gubienia animacji; **limit 6 jednoczesnych połączeń**,
   żeby nie wyczerpać skończonej puli gniazd lwIP; oraz **handler wyjątków pętli
   zdarzeń**, który zapisuje do logu traceback każdego zadania, jakie padło.

   Dozór sam się kalibruje: sprawdza najpierw, czy sonda w ogóle działa na danym
   firmware (pętla zwrotna w lwIP), i jeśli nie — wyłącza się, zamiast restartować
   serwer bez powodu.

Jeśli mimo tego problem wróci, zajrzyj do logu — powie, co się stało i po ilu
godzinach.

### Co czytać w logu

Linia stanu co 5 minut wygląda tak:

```
02:35:11  RAM 138912 B | polaczenia otwarte 0 | obsluzonych 214
```

Trzy liczby rozstrzygają, która hipoteza jest prawdziwa:

| Objaw w logu | Znaczenie |
|---|---|
| RAM systematycznie spada | wyciek pamięci — log pokaże, po ilu godzinach się zaczyna |
| „połączenia otwarte" rośnie i nie wraca do zera | gniazda nie są zwalniane, pula lwIP się kończy |
| „obsłużonych" zamarza, choć wchodzisz na panel | zapytania nie dochodzą — czyli WiFi, nie serwer |
| wpis `ZADANIE PADLO` | coś rzuciło wyjątkiem; traceback mówi dokładnie co |
| wpis `nasluch nie przyjmuje polaczen` | to był serwer, i dozór go podniósł |

### Log

Ustawienia → **Diagnostyka**. Domyślnie włączony zapis do `log.txt` na Pico.
Do pliku idą tylko istotne zdarzenia (start, stan sieci, wznawianie, wolna pamięć
co 5 minut, błędy); pojedyncze wejścia na panel lecą wyłącznie na port szeregowy,
żeby nie zajeżdżać pamięci flash. Plik nie rośnie ponad ~12 kB — po przekroczeniu
starsze wpisy są obcinane.

Każdy wpis ma stempel **czasu od startu** (`gg:mm:ss`), bo Pico nie ma zegara
z baterią. To i tak najważniejsza informacja: po ilu godzinach pracy coś się stało.

Trzy sposoby odczytu:

```bash
mpremote connect auto fs cat :log.txt      # przez USB
```

- w panelu: Ustawienia → Diagnostyka → **Pokaż log**
- na porcie szeregowym na żywo (tam widać też każde zapytanie HTTP)

**Jak wyłączyć:** odznacz *„Zapisuj zdarzenia do pliku log.txt"* w Diagnostyce
i kliknij Zapisz. Port szeregowy dalej będzie pisał — to nic nie kosztuje.
Żeby wyciszyć również log zapytań HTTP na porcie szeregowym, ustaw `LOG = False`
na początku `webserver.py`. Plik usuniesz przez `mpremote connect auto fs rm :log.txt`.

**Nie wiem, jaki ma adres** → patrz „Jak wejść do panelu nie znając adresu IP" wyżej.
Najpewniejsza droga: podłącz telefon do sieci `LED-Lampka` i wejdź na `192.168.4.1`.

**`lampka.local` nie działa** → Twój firmware nie ma odpowiedzi mDNS, albo klient jej
nie obsługuje (część Androidów, przeglądarki w trybie oszczędzania danych). Wpisuj
adres z `http://` na początku, bo bez tego telefon potraktuje to jako zapytanie do
wyszukiwarki. Jeśli i tak nie idzie — zostaje AP `192.168.4.1`, który działa zawsze.

**W nowym miejscu lampka nie widzi WiFi** → sama wróci do trybu AP po ~15 s prób,
więc po prostu podłącz się do `LED-Lampka` i wpisz dane nowej sieci.

## Struktura

```
firmware/        wszystko, co ląduje na Pico
main.py          start: WiFi, sygnały, uruchomienie zadań
config.py        piny, rozmiar matrycy, ustawienia + zapis do settings.json
led_matrix.py    klasa Matrix: jeden NeoPixel, mapowanie wężyka, jasność
animations.py    wszystkie animacje (klasa Anim + rejestr ANIMS)
lamp.py          stan lampki, pętla rysowania, auto-wyłączanie, obsługa gestów
touch.py         TTP223: krótko / przytrzymanie / długie przytrzymanie
netmgr.py        łączenie z WiFi, tryb AP, skanowanie
dns.py           serwer DNS dla captive portalu (panel otwiera się sam)
logger.py        log zdarzeń: port szeregowy + opcjonalnie log.txt
webserver.py     serwer HTTP + API (uasyncio, bez bibliotek zewnętrznych)
frames.py        galeria własnych animacji (katalog anims/)
glyphs.py        czcionka 3×5 do pokazania IP na matrycy
www/             panel: index.html, style.css, app.js
                 (powyższe leżą w firmware/)
cad/             obudowa: pliki STL do druku
```

`settings.json` i katalog `anims/` tworzą się same przy pierwszym zapisie.
Sam program to ~95 kB z ~1,4 MB flasha Pico.

### Dlaczego efekty nie obciążają Pico

Cała obróbka dzieje się **w przeglądarce** i zapieka się w piksele. Na lampkę
trafiają gotowe klatki, a ona robi dokładnie to samo co przy zwykłym obrazku:
jeden `blit()` bufora 189 bajtów na klatkę. Możesz nakładać dowolnie dużo efektów
— koszt po stronie Pico jest zawsze taki sam. Cena tego rozwiązania: efekty są
nieodwracalne (po zejściu do 0 % koloru nie ma skąd go wziąć), dlatego jest
cofanie na 40 kroków.

Trzy zabezpieczenia przed zamuleniem lampki:

1. **Limit 40 klatek** — generatory nie przekraczają go po cichu, tylko dokładają
   tyle, ile się mieści, i mówią o tym wprost.
2. **Limit 64 kB na zapytanie HTTP** — większe ciało dostaje `413` bez próby
   wczytania do RAM-u. Pełna 40-klatkowa animacja waży ~16 kB, więc jest z zapasem.
3. **Do RAM-u wchodzi tylko grająca animacja** — 40 klatek to 7,5 kB buforów.

### Jak trzymane są własne animacje

Każda animacja to osobny plik `anims/<nazwa>.json`, a `anims/index.json` to spis nazw
z miniaturami. Do RAM-u ładowana jest wyłącznie ta animacja, która akurat gra —
przy 24 animacjach po 40 klatek cała galeria w pamięci by się nie zmieściła.
Piksele siedzą jako ciąg hex (`rrggbb` × 63), bo lista liczb w JSON-ie zajmuje
trzy razy więcej. Klatka na urządzeniu to gotowy bufor 189 bajtów wrzucany do matrycy
jednym `blit()`, bez przeliczania piksel po pikselu.

Limity: **40 klatek** na animację, **24 animacje** w galerii, czas klatki **40–10000 ms**.
Panel dostaje te wartości z `/api/state`, więc zmiana ich w `frames.py` od razu
przestawia też podpowiedzi w interfejsie.

## Licencja

**[CC BY-NC 4.0](LICENSE)** — uznanie autorstwa, użycie niekomercyjne.

Możesz zbudować dla siebie, przerobić, opublikować swoją wersję z podaniem źródła,
używać na warsztatach i w edukacji. **Sprzedaż gotowych lampek, zestawów albo
wydrukowanych paneli wymaga pisemnej zgody** autora.

Pamiętaj, że CC BY-NC celowo **nie jest** licencją open source w rozumieniu OSI —
ograniczenie komercyjne jest tu zamierzone. Składniki obce (MicroPython, SDK Pico W,
narzędzia zewnętrzne) mają własne licencje.

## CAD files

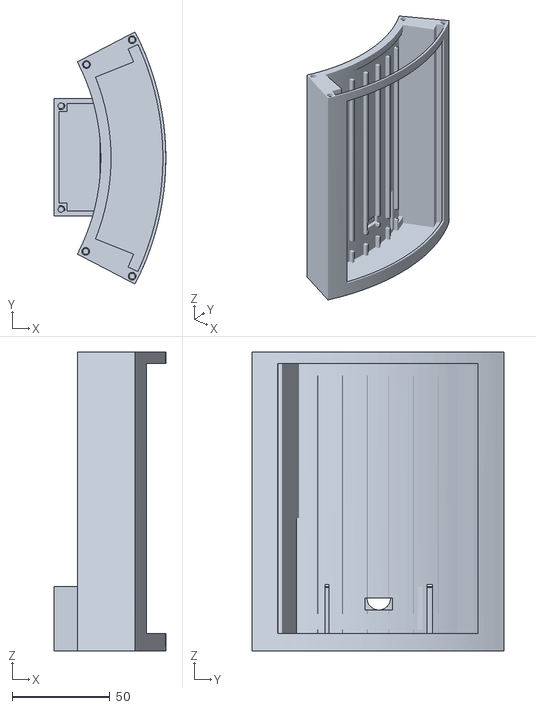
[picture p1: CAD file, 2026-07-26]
cad/stl/case-main.stl
57.2 x 129.1 x 153.0

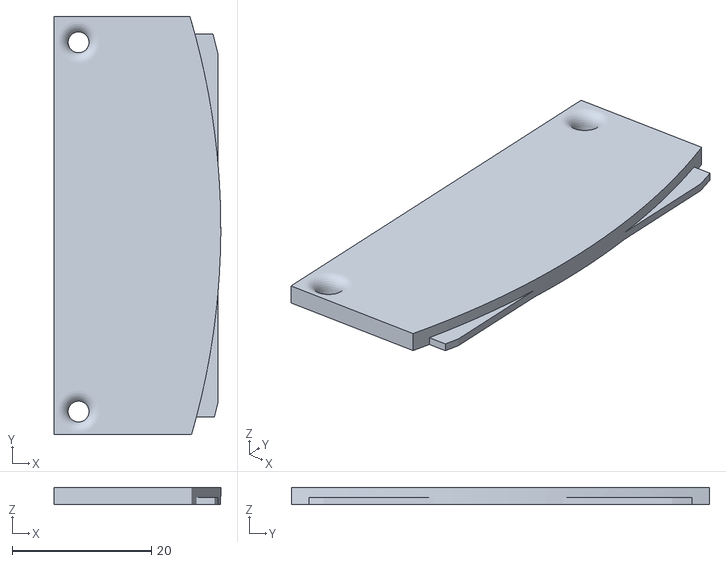
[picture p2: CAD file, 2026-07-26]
cad/stl/cover-pico.stl
23.9 x 60.0 x 2.50

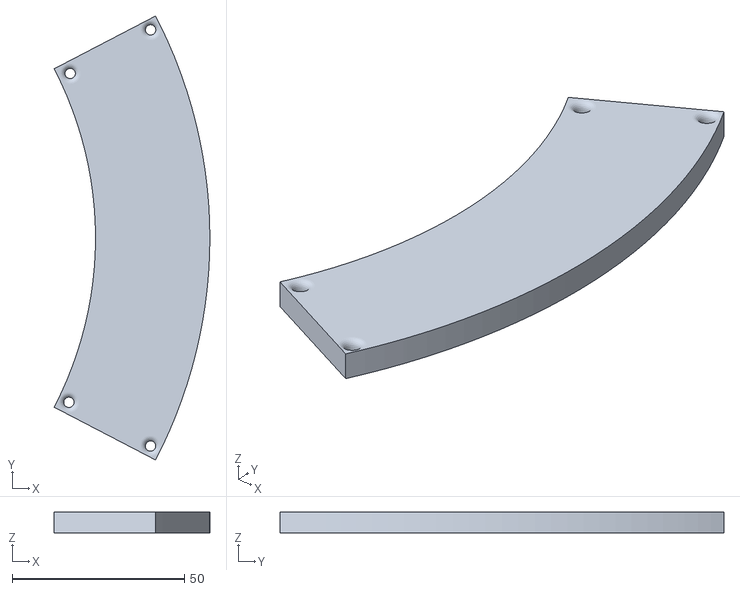
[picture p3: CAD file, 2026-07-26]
cad/stl/cover.stl
45.3 x 129.1 x 6.00

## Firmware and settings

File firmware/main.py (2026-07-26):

# LED Lampka - ramka 7 x 9 WS2812 na Raspberry Pi Pico W
#
# Start:
#   1. wczytanie ustawien
#   2. WiFi: zapisana siec, a jak sie nie uda - wlasny AP "LED-Lampka"
#   3. pokazanie ostatniego czlonu IP na matrycy
#   4. rownolegle: animacje + przycisk + serwer panelu
import time

import machine

try:
    import uasyncio as asyncio
except ImportError:
    import asyncio

import config
import dns
import glyphs
import logger
import netmgr
import touch
from lamp import Lamp
from webserver import Server


def forget_wifi():
    """Wywolywane bardzo dlugim przytrzymaniem dotyku - awaryjny powrot do AP."""
    print("czyszcze ustawienia WiFi i restartuje")
    config.settings["wifi_ssid"] = ""
    config.settings["wifi_pass"] = ""
    config.save()
    time.sleep_ms(200)
    machine.reset()


async def start():
    try:
        asyncio.get_event_loop().set_exception_handler(logger.task_error)
    except (AttributeError, TypeError):
        pass          # starsze uasyncio nie ma tego mechanizmu
    config.load()
    lamp = Lamp()
    s = config.settings

    glyphs.flash(lamp.m, (0, 0, 40))              # zyje

    netmgr.set_country(s["country"])
    host = netmgr.clean_hostname(s["hostname"])
    ip = None
    err = ""
    if s["wifi_ssid"]:
        print("lacze z", s["wifi_ssid"])
        glyphs.flash(lamp.m, (60, 30, 0))         # zolty blysk: lacze sie
        ip, err = await netmgr.connect(s["wifi_ssid"], s["wifi_pass"], host)
        if err:
            print("WiFi nie wyszlo:", err)

    ap_ip = None
    if ip:
        glyphs.flash(lamp.m, (0, 60, 0))          # zielony: jest siec
        # Zapasowe wejscie: wlasny AP obok domowego WiFi. Dzieki temu lampka jest
        # osiagalna nawet tam, gdzie nie wiadomo jaki dostala adres.
        if s["ap_always"]:
            ap_ip = netmgr.start_ap(s["ap_pass"])
        lamp.net = {"mode": "sta+ap" if ap_ip else "sta", "ip": ip,
                    "ssid": s["wifi_ssid"], "host": host, "ap_ip": ap_ip,
                    "err": "", "trying": False, "rssi": netmgr.rssi_of(netmgr.network.WLAN(netmgr.network.STA_IF))}
    else:
        ap_ip = netmgr.start_ap(s["ap_pass"])
        lamp.net = {"mode": "ap", "ip": ap_ip or "-", "ssid": config.AP_SSID,
                    "host": host, "ap_ip": ap_ip, "err": err, "trying": False, "rssi": None}
        glyphs.flash(lamp.m, (0, 0, 90), 2)       # niebieski x2: tryb AP

    logger.log("start; siec:", lamp.net["mode"], "adres:", lamp.net["ip"])
    print("panel:")
    if ip:
        print("   http://%s.local/   (nazwa hosta, mDNS)" % host)
        print("   http://%s/" % ip)
    if ap_ip:
        print("   http://%s/   po podlaczeniu do sieci '%s' (haslo: %s)"
              % (ap_ip, config.AP_SSID, s["ap_pass"]))

    if s["show_ip"] and ip:
        glyphs.show_ip(lamp.m, ip)

    btn = touch.Touch(active_high=s["btn_active_high"])
    server = Server(lamp)
    # Captive portal TYLKO w czystym trybie AP. Gdy lampka siedzi w domowym
    # WiFi, serwer DNS odpowiadalby na zapytania z calej sieci lokalnej
    # (kazda nazwa -> 192.168.4.1), a to psuje internet innym urzadzeniom.
    if ap_ip and not ip and s["captive"]:
        server.portal_ip = ap_ip
        asyncio.create_task(dns.serve(ap_ip))
        print("captive portal: panel otworzy sie sam po podlaczeniu do AP")
    await server.start()

    asyncio.create_task(lamp.button_loop(btn, forget_wifi))
    asyncio.create_task(lamp.save_loop())
    asyncio.create_task(netmgr.watchdog(lamp))     # wznawia zerwane WiFi
    asyncio.create_task(server.supervisor())       # pilnuje nasluchu HTTP
    asyncio.create_task(housekeeping(server))      # porzadki + raport stanu
    await lamp.run()


async def housekeeping(server):
    """Co 5 minut sprzata pamiec i zapisuje stan.

    Trzy liczby w jednej linii rozstrzygaja, co sie dzieje przez noc:
    spadajacy RAM = wyciek, rosnaca liczba otwartych polaczen = gniazda nie sa
    zwalniane, zamarznieta liczba obsluzonych = nasluch przestal odbierac."""
    import gc
    while True:
        gc.collect()
        try:
            free = gc.mem_free()
        except AttributeError:
            free = -1
        logger.log("RAM %d B | polaczenia otwarte %d | obsluzonych %d | %s"
                   % (free, server.open_conns, server.served, netmgr.link_info()))
        await asyncio.sleep(300)


try:
    asyncio.run(start())
except KeyboardInterrupt:
    print("zatrzymane z klawiatury")
except Exception as e:
    # Nie zostawiaj lampki swiecacej byle czym, jak cos padnie
    print("KRYTYCZNY BLAD:", e)
    try:
        import neopixel

        np = neopixel.NeoPixel(machine.Pin(config.LED_PIN), config.LED_COUNT)
        for _ in range(3):
            np.fill((60, 0, 0))
            np.write()
            time.sleep_ms(250)
            np.fill((0, 0, 0))
            np.write()
            time.sleep_ms(250)
    except Exception:
        pass
    raise

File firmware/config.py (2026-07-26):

# Konfiguracja LED Lampki - ramka 7 x 9 na Raspberry Pi Pico W
#
# SPRZET (zmieniaj tylko jesli przelutujesz):
#   GP0  -> DIN matrycy WS2812 (przez rezystor 330 om)
#   GP2  -> OUT z TTP223 (modul zasilany z 3V3, pin 36)
#   5V   -> zasilacz zewnetrzny (VSYS pin 39 przez diode Schottky)
import json

LED_PIN = 0
BUTTON_PIN = 2

WIDTH = 7
HEIGHT = 9
LED_COUNT = WIDTH * HEIGHT  # 63

SETTINGS_FILE = "settings.json"
# wlasne animacje siedza w katalogu anims/ - patrz frames.py

AP_SSID = "LED-Lampka"

DEFAULTS = {
    "on": True,
    "anim": "ogien",
    "brightness": 40,        # %
    "speed": 100,            # % szybkosci animacji
    "color": "#ff7800",      # kolor dla trybow Kolor / Oddech
    "auto_off": False,
    "auto_off_min": 60,      # minuty bezczynnosci do zgasniecia
    "wifi_ssid": "",
    "wifi_pass": "",
    "ap_pass": "ledlampka",  # min. 8 znakow
    "hostname": "lampka",    # panel pod http://lampka.local/
    # Wlasny AP utrzymywany obok domowego WiFi - drugie, niezalezne wejscie
    # do panelu. Pico W dzieli jedno radio miedzy oba interfejsy, wiec na
    # niektorych routerach potrafi to rozchwiac polaczenie; jesli lampka ma
    # poprawny adres, a panel nie odpowiada, sprobuj to wylaczyc.
    "ap_always": True,
    "captive": True,         # po podlaczeniu do sieci lampki sam otworz panel
    "country": "PL",         # kod kraju = dozwolone kanaly WiFi (12 i 13!)
    # Oszczedzanie energii radia usypia odbiornik i gubi pakiety przychodzace -
    # po godzinach pracy lampka "jest w sieci", ale panel nie odpowiada.
    "wifi_powersave": False,
    # Ponizej tej sily sygnalu polaczenie formalnie trwa, ale ruch przychodzacy
    # ginie. Lampka probuje wtedy przepiac sie na mocniejszy nadajnik.
    "rssi_min": -78,
    "log_file": True,        # zapisuj zdarzenia do log.txt
    "btn_active_high": True, # TTP223 domyslnie daje stan wysoki przy dotyku
    # Geometria tasmy w ramce: pierwsza dioda w prawym DOLNYM rogu, pasek idzie
    # w GORE, zawraca i schodzi w dol - czyli kolumnami, wezykiem.
    "origin": "BR",          # rog z pierwsza dioda: BL BR TL TR (patrzac z przodu)
    "rows": False,           # True = pasek biegnie rzedami, False = kolumnami
    "serpentine": True,      # wezykiem
    "show_ip": True,         # po starcie pokaz ostatni czlon IP na matrycy
    # tryby WYLACZONE z przelaczania przyciskiem (w panelu dalej dostepne)
    "seq_off": ["kalibracja"],
}

settings = dict(DEFAULTS)

_dirty = False


def load():
    """Wczytuje settings.json na wierzch wartosci domyslnych."""
    try:
        with open(SETTINGS_FILE) as f:
            data = json.load(f)
        for k in DEFAULTS:
            if k in data:
                settings[k] = data[k]
    except (OSError, ValueError):
        pass  # pierwszy start albo uszkodzony plik - zostaja domyslne
    return settings


def save():
    global _dirty
    try:
        with open(SETTINGS_FILE, "w") as f:
            json.dump(settings, f)
        _dirty = False
        return True
    except OSError as e:
        print("nie zapisano settings.json:", e)
        return False


def mark():
    """Oznacza zmiane do zapisu. Realny zapis robi flush() co kilka sekund,
    zeby klikanie przyciskiem nie zajezdzalo pamieci flash."""
    global _dirty
    _dirty = True


def flush():
    if _dirty:
        save()
        return True
    return False


def hex_to_rgb(h):
    try:
        v = int(str(h).lstrip("#"), 16)
    except ValueError:
        return (255, 255, 255)
    return ((v >> 16) & 255, (v >> 8) & 255, v & 255)


def color_rgb():
    return hex_to_rgb(settings["color"])

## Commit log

2026-07-26 Initial release: pixel frame firmware, web panel and enclosure models
    A 3D-printed lithophane picture frame driven by a 7x9 WS2812 matrix on a
    Raspberry Pi Pico W. The device serves everything itself - no cloud, no
    companion app, no libraries beyond stock MicroPython.
    Firmware (firmware/)
    - 17 built-in animations written for the portrait 7x9 grid
    - one NeoPixel buffer behind a configurable serpentine mapping, so
    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
    [case-main.stl, cover-pico.stl, cover.stl]
2026-07-26 Docs: mark diode, resistor and capacitor as optional
    The reference build runs without them. They move from the required bill of
    materials into a separate "optional" table that says what each one protects
    against, so anyone can decide whether their build needs them.
    Wiring table, ASCII diagram and power notes updated to match.
2026-07-26 Make the listener supervisor work without lwIP loopback
    The self-healing HTTP listener never armed on real hardware: it probes its
    own port to tell whether the accept loop is alive, and some MicroPython
    builds have no loopback interface, so the probe failed and the supervisor
    disabled itself on every boot.
    It now tries the loopback address, then the station address, then the access
    point address, and remembers whichever one answered. The supervisor only
    gives up when none of them accept a connection.
    Also log the radio state in the periodic status line - link, RSSI, channel
    and whether the access point is up. A lamp that holds an address while no
    request ever reaches it looks identical to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
    [main.py, netmgr.py, webserver.py]
2026-07-26 Pick the strongest access point instead of letting the driver guess
    Field logs showed the lamp associating with two different access points on
    alternating boots: channel 1 at -53..-60 dBm, or channel 6 at -81..-88 dBm.
    On the weak one the link stayed nominally up - the lamp kept its address and
    the reconnect watchdog never fired - but inbound packets were lost, so the
    panel froze mid-use and would not reload. Same firmware, same network, the
    only difference was which transmitter answered first.
    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
2026-07-26 Only re-associate when a stronger transmitter actually exists
    The previous commit tore the link down every minute whenever the signal sat
    below the threshold, regardless of whether anything better was in range. In
    a location served by a single access point that is destructive: a weak but
    usable link gets dropped and rebuilt every 60 seconds, and the lamp spends
    several of those seconds fully offline.
    The watchdog now scans first and compares. It re-associates only if the best
    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
2026-07-26 Warn about weak signal in the WiFi and Settings tabs
    A lamp on a marginal link keeps its address and looks fine until the panel
    stops responding mid-use. The reading was already in the log and the WiFi
    status line, but only if you went looking for it.
    A banner now appears above both tabs whenever the link is weak, carrying the
    measured value: an amber notice below -70 dBm, a red one below the device's
    rssi_min threshold explaining that packets are being lost and what to do
    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
